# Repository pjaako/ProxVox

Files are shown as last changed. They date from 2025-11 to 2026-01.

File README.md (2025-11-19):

# ProxVox*
ProxVox* is a one-off hardware build: fitting a Linux/Proxmox server, NAS, and audio streamer into a vintage amplifier. This repo includes the BOM, STEP/DXF, and simple wiring/circuit notes—mostly for my own use. ****Not affiliated, sponsored, or endorsed by [Proxmox](https://github.com/proxmox).***

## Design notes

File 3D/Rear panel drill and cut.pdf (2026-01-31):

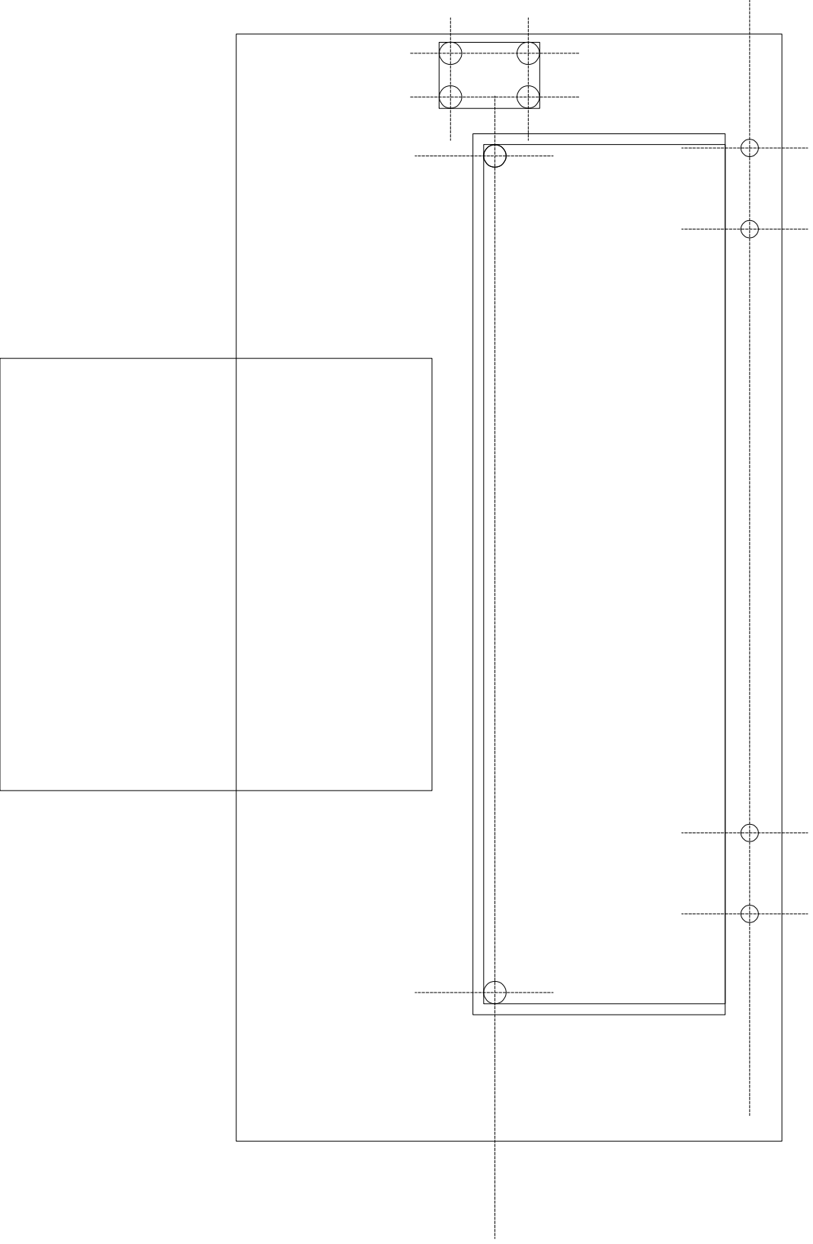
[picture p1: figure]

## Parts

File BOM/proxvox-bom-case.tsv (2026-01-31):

Line | What | What for | What I Bought | Qty | Where I Bought It | What I paid (EUR) | Comment
1 | Old, amplifier with aesthetics I like | Case with 80’s vibe | TECHNICS SU-Z25 (defunct) | 1 | ebay.de | 30 | _
2 | Mounting frame for 2 x 3,5” HDDs | Mount my HDDs inside the case | PHANTEKS HDD Mounting Frames, 2x 3,5", Stackable | 1 | amazon.de | 11 | _
3 | 150 x 150 x 0,25 mm Thermal Pad, one side adhesive | HDD cooling and vibration damping | T-Global GT10D-150-150-0.25-1A | 1 | DigiKey 1168-GT10D-150-150-0.25-1A-ND | 5 | _
4 | 35 x 35 x 0,25 mm Thermal Pad, both sides adhesive | HDD cooling and vibration damping | 3M 8810SQ-35(100) | 4 | Digikey 1067-8810SQ-35(100)-ND | 5 | _
5 | 25 x 240 x 1 mm Thermal Pad, one side adhesive | HDD cooling and vibration damping | 3M 5590H | 1 | TME 3M-5590-25-240-1.0 | 5 | _
6 | Hexagonal polyurethane foam bumpers, 11 x 3 mm | New feet for the amp | 3M SJ-5201-LIGHT-BROWN | 132 | Digikey 3M157589-ND | 7 | _
7 | Very strong double sided adhesive film | Fasten parts without screws | 3M 5981-035-4-11 | 1 | Digikey 1067-5981-035-4-11-ND | 5 | 4.00" X 11.00" (100 x 280 mm) VHB sheet, ~0.5mm thick
8 | IDC connectors 10 positions | Wiring power switch, audio, maybe USB | Würth Elektronik 61201023021 | 4 | Digikey 732-2102-ND | 1 | _
9 | Ribbon cable | Wiring power switch, audio, maybe USB | 3M 3302/50 100, ft. | 2 | Digikey 19-3302/50100-DS-ND | 10 | 50 conductors zippable cable, will suffice for all wiring
10 | Polarising key for IDC connectors | Always plug connectors right the 1st time | Harwin M20-003 | 10 | Digikey 952-2360-ND | 2 | _
11 | Plastic standoffs, M3 x 11 mm | Attach the motherboard to mounts | Essentra MTNSP-M3-11-1 | 3 | DigiKey MTNSP-M3-11-1-ND | 4 | Non-conductive to avoid multiple ground points
12 | Brass standoff, M3 x 11 mm | Attach the motherboard to mounts | Würth Elektronik 970110324 | 2 | DigiKey 732-12849-ND | 1 | Conductive to provide reliable grounding point (which IO shield is not)

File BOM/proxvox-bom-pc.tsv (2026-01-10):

Line | What | What for | What I Bought | Qty | Where I Bought It | What I paid (EUR) | Comment
1 | ITX Motherboard with barrel (”DC”, ”brick”) connector | Server part | ASROCK N100DC-ITX | 1 | alza.de | 125 | _
2 | DDR4 Module | Server part | SK Hynix 16GB DDR4-3200 (used) | 1 | ebay.de | 20 | should have gone with 32Gb from the beginning, who knew it was gonna get THAT expensive...
3 | NVMe Drive | Server part | WD Black SN7100 (500 GB, M.2 2280) | 1 | galaxus.de | 51 | should do it for <10 VMs
4 | 3,5” HDDs | NAS | Seagate ST12000DM0007 BarraCuda Pro + 12TB 3,5” 256MB Cache (recertified) | 2 | ebay.de | 228 | not exactly a NAS model but the price for the recertified drives was too good (bought before the scam wave)
5 | 35mm high 140x140mm fan | Good airflow at minimal RPM | CORSAIR RS140 MAX 140mm | 1 | amazon.de | 12 | 30mm thick fan should suck in enough fresh cold air even at minimal RPM
6 | 2,5Gbps PCIe network card | Faster networking and passthrough to a VM | Intel I226T1 | 1 | 25n.de | 51 | I see no value in investing in a 10Gb switch at current price
7 | CNVio Wi-Fi/BT card | My workbench has no wired connection... | no-name AX211NGW CNVio2 | 1 | amazon.de | 35 | _
8 | 19V powerbrick not less than 100W | Powering all of the above and more | Delta SADP-135EB 19V 7A (used) | 1 | ebay.de | 10 | _

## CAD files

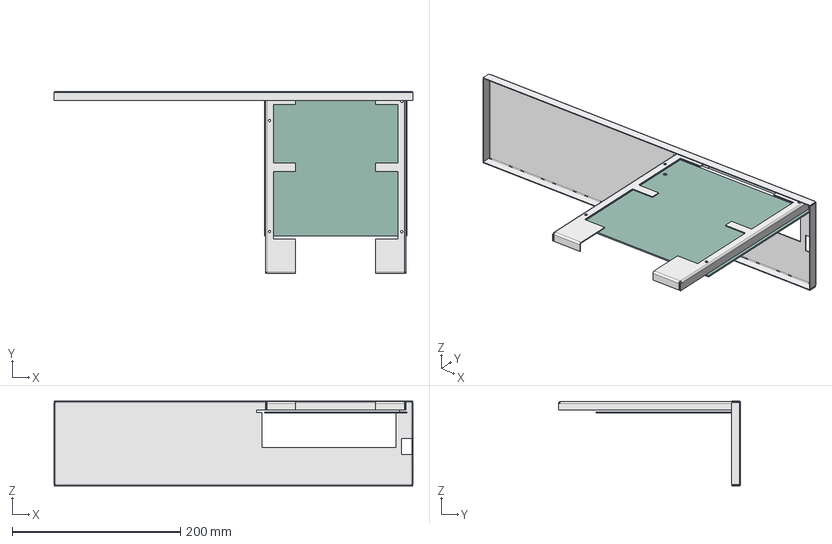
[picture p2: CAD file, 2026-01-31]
3D/ProxVox Assy.step
427.0 x 216.8 x 101.0 mm
ITX Motherboard v5
Bitphonic back plate
Bitphonic motherboard bracket
Bitphonic motherboard bracket (1)

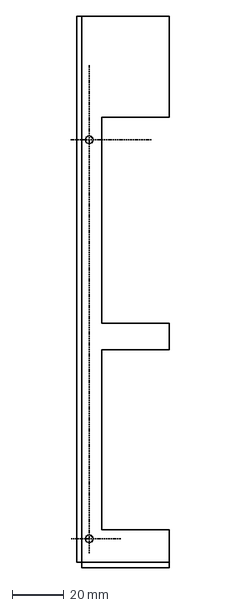
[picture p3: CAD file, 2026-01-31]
3D/right bracket top drill.dxf
38.2 x 214.0 mm

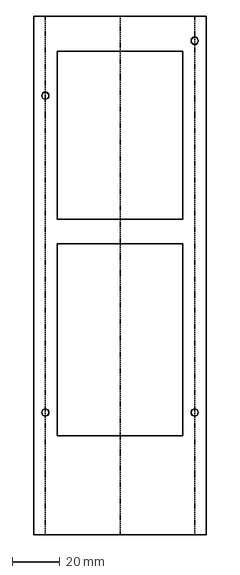
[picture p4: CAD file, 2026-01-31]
3D/Motherboard brackets drill and cut.dxf
72.0 x 216.0 mm

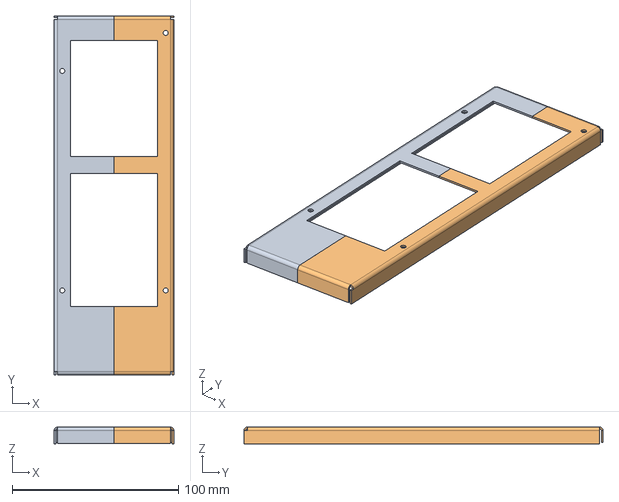
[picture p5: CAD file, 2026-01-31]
3D/ProxVox motherboard brackets.step
72.0 x 216.0 x 10.2 mm

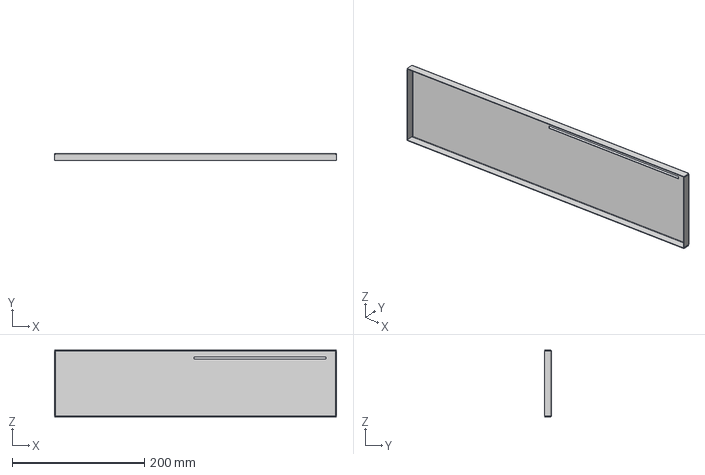
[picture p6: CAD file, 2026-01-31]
3D/ProxVox back plate.step
427.0 x 11.0 x 101.0 mm

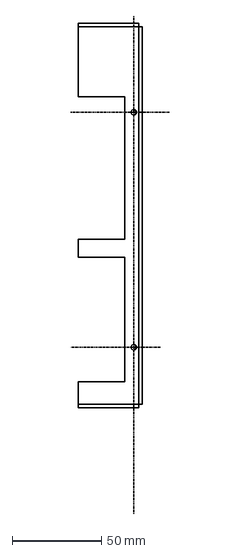
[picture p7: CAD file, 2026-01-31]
3D/left bracket top drill.dxf
55.2 x 279.7 mm

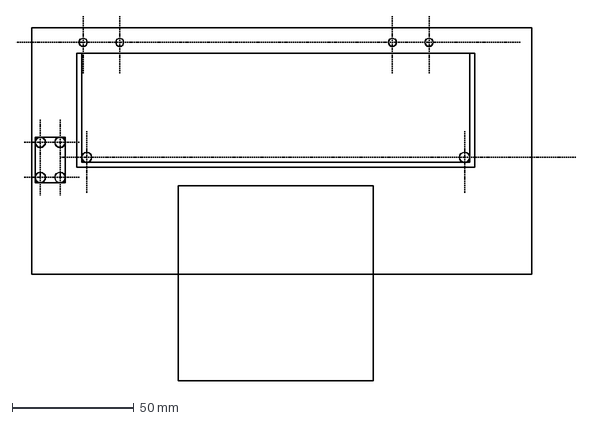
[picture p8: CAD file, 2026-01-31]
3D/Rear panel drill and cut.dxf
229.4 x 149.6 mm

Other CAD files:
3D/ATX IO Shield and aperture.step
3D/ITX Motherboard.step
3D/ATX Constraints.step
3D/ATX Constraints.f3d
3D/ATX IO Shield and aperture.f3d
3D/ITX Motherboard.f3d
3D/ProxVox Assy.f3d
3D/ProxVox back plate.f3d
3D/ProxVox motherboard brackets.f3d

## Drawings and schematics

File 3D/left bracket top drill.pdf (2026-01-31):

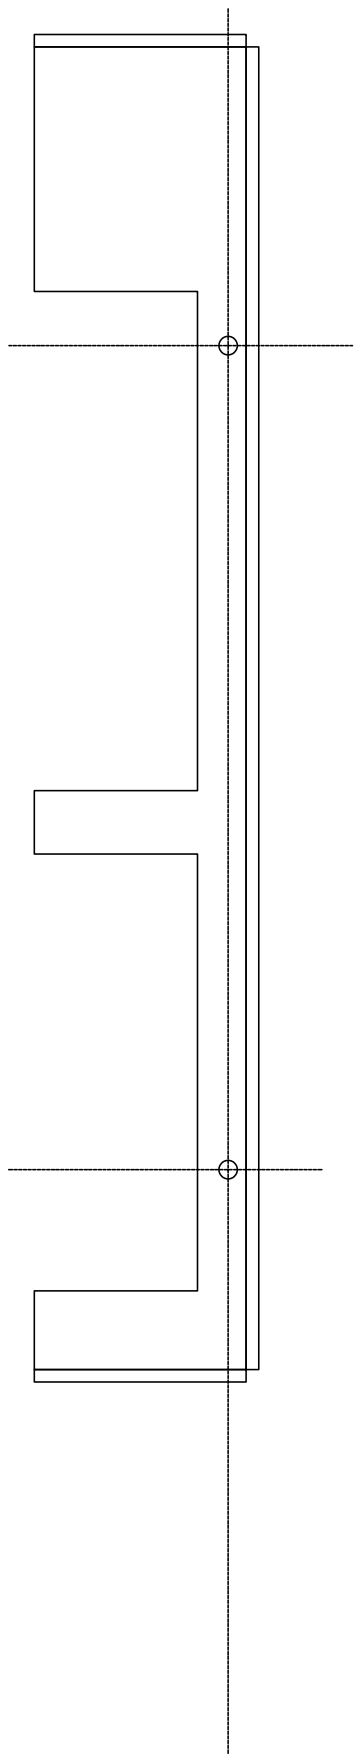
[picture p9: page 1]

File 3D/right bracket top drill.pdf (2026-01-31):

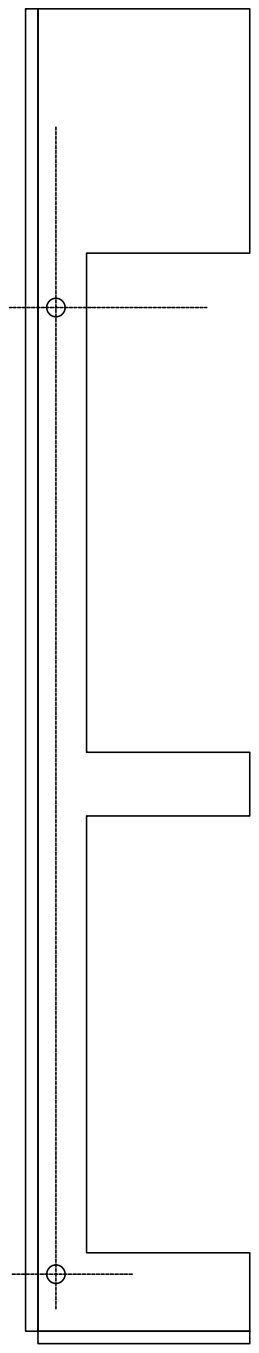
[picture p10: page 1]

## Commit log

2025-11-19 started a bill of materials for PC parts
    [proxvox-bom-pc.tsv]
2025-11-19 Fix quotation marks in proxvox-bom-pc.tsv
    Github TSV parser won't allow double quotes.
    [proxvox-bom-pc.tsv]
2025-11-23 filled PC parts BOM table
    [proxvox-bom-pc.tsv]
2025-11-23 edited PC parts BOM table
    [proxvox-bom-pc.tsv]
2025-11-23 line endings
    [proxvox-bom-pc.tsv]
2025-11-28 WiFi/BT Card added in BOM
    [proxvox-bom-pc.tsv]
2025-11-28 added BOM for casing parts
    [proxvox-bom-case.tsv]
2025-11-30 'Kicad file for wiring created
    [ProxVox-wiring.kicad_sch]
2025-12-10 wysiwyg symbols for IDC connectors
2025-12-10 wiring for power button added
    [ProxVox-wiring.kicad_sch]
2026-01-10 DDR price explosion rant
    [proxvox-bom-pc.tsv]
2026-01-31 3D models added
    [ATX Constraints.f3d, ATX Constraints.step, ATX IO Shield and aperture.f3d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]
2026-01-31 fasteners added
    [proxvox-bom-case.tsv]
2026-03-25 added a wysiwyg symbol for wiring mikroe AudioAmp 8 Click
2026-04-03 gone too far drawing a KiCad symbol fritzling-style? maybe
2026-04-04 Added (fritzing-style) symbol for mikroe-5312 USB To I2C interface
2026-04-06 Pictorial circuit diagram of audio amplifier started
    [ProxVox-wiring.kicad_sch]
2026-07-18 Add KiCad .bak files to .gitignore
2026-07-21 added pictorial-style symbols for used amp click boards: AudioAmp 8 Click PN: MIKROE-4812 Headphone AMP 3 Click PN: MIKROE-5721
2026-07-21 audio wiring documentation started
    [amplifier.kicad_sch, power-button.kicad_sch]
2026-07-21 deleted local-only KiCad files
2026-07-21 project renaming started with KiCad files
    [Serverola-wiring.kicad_sch, amplifier.kicad_sch, power-button.kicad_sch]
